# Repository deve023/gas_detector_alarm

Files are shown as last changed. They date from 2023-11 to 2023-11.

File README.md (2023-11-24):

# Gas Detector Alarm

The system has a gas detector. When gas is detected a yellow LED turns on and an alarm buzzer rings. When gas is no longer present, the LED turns off but the sound alarm remains until the user presses the deactivation button. Cost: aproximately USD 16 if the components are purchased through Amazon.

# Block Diagram

BlockDiagram

The repository contains the VHD code describing the hardware, a test bench to try out the different scenarios and the circuit diagram. 3D design of the case is pending.

# Bill of Materials

BOM

# Case Example

In this scenario, pressing the button when the alarm is off does not change the output. Once gas is detected, LED and buzzer both turn on. If gas is no longer detected, LED goes off but buzzer remains. Only when pressing the button does the buzzer turn off. Furthermore, if gas is detected when the button is on, the user must release the button and press it again to deactivate the alarm. This last functionality is set like this in case the button gets stuck, if that is the case and the user is unaware of the button's condition the alarm would go off anyway.

Example

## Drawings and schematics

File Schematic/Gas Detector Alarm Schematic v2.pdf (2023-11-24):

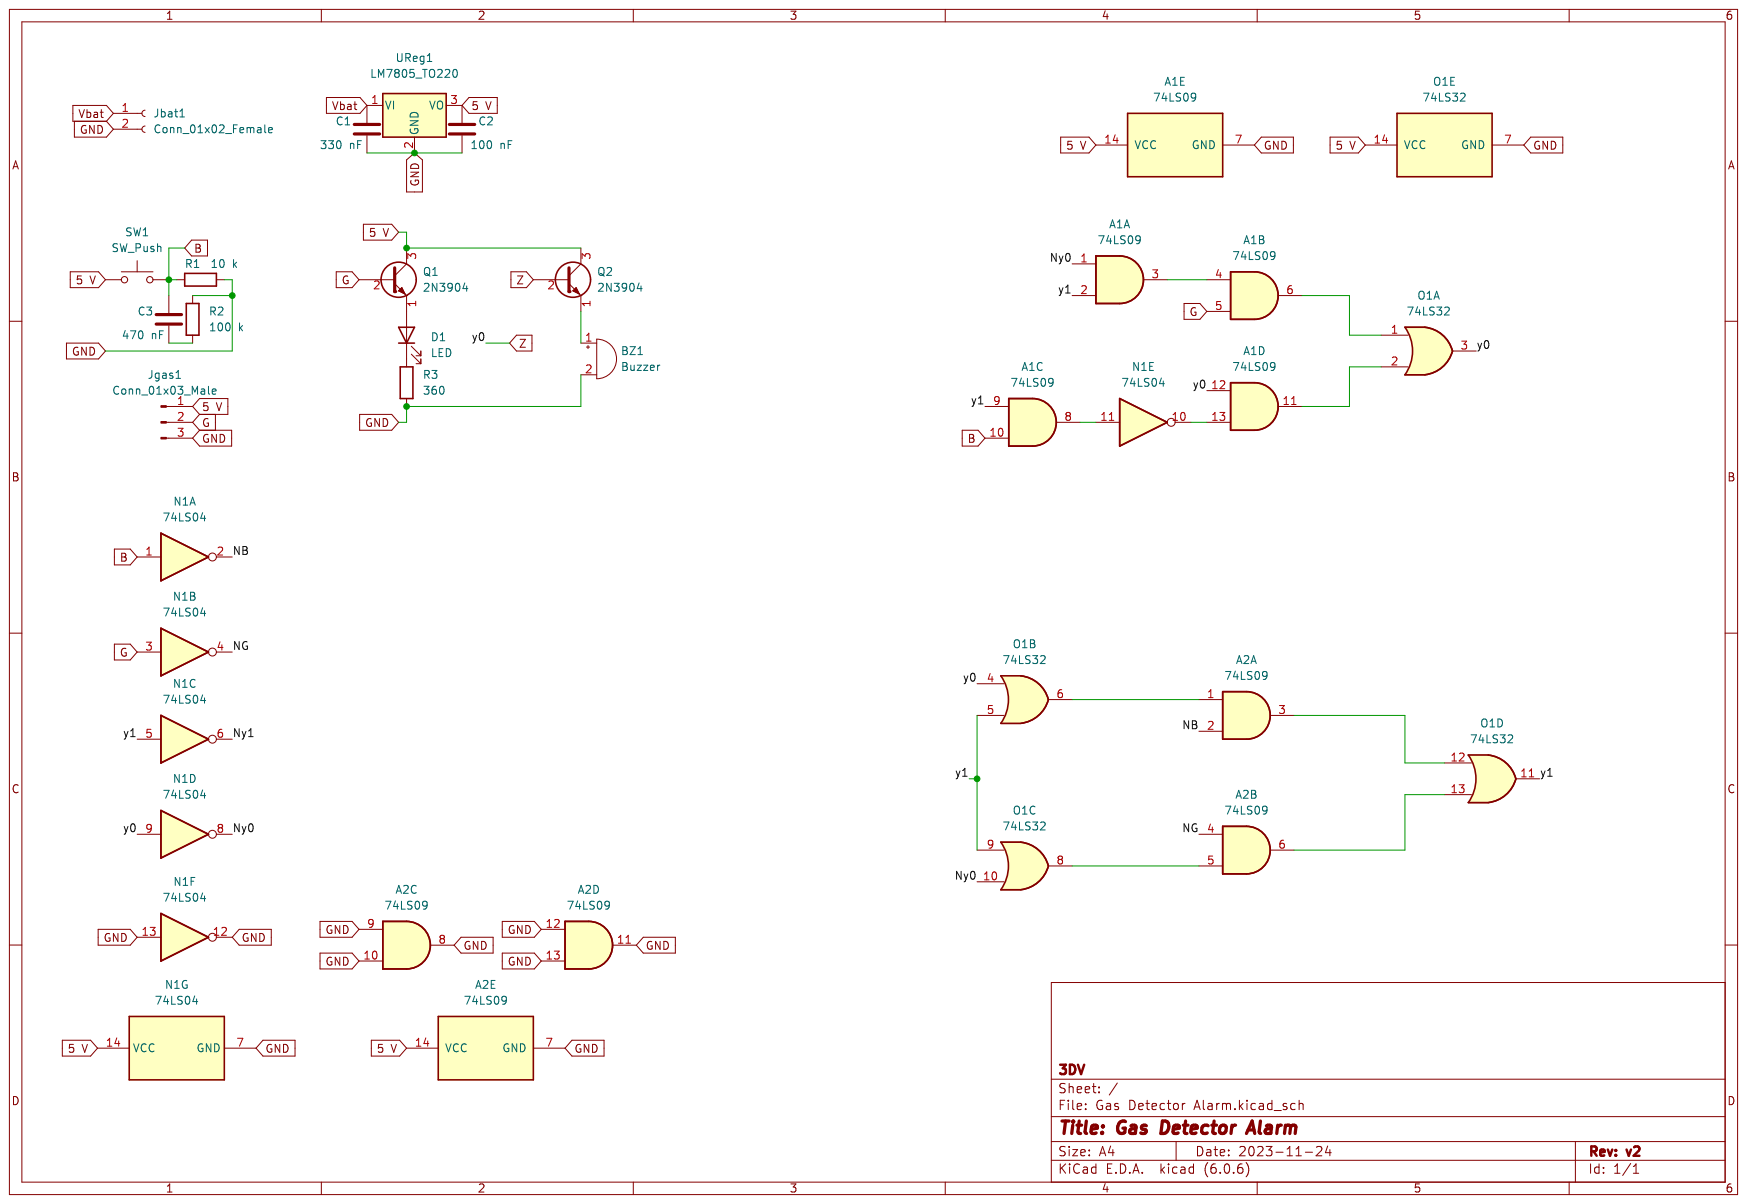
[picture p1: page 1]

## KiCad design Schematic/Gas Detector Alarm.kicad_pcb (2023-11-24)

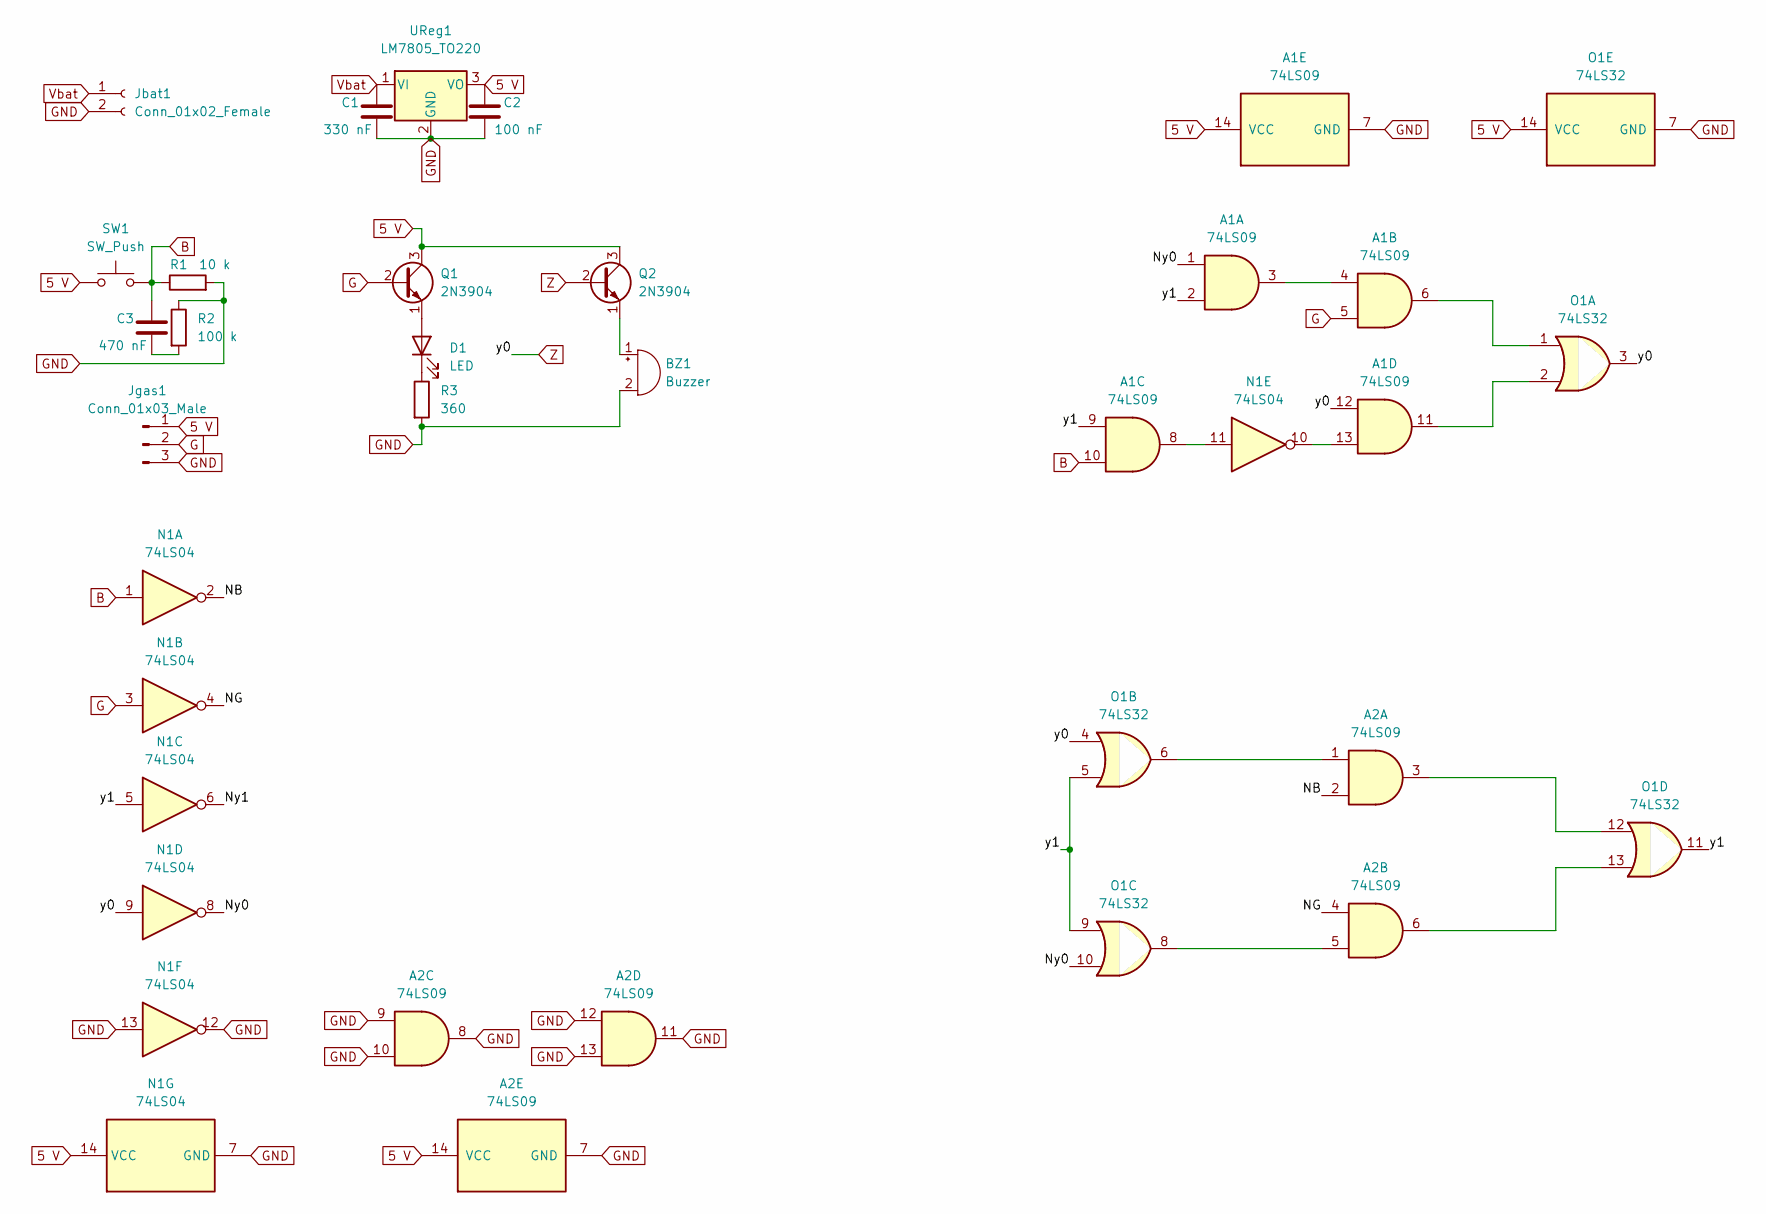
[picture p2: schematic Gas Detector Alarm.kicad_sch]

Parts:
A1, A2: 74LS09; DIP_Socket-14_W4.3_W5.08_W7.62_W10.16_W10.9_3M_214-3339-00-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
BZ1: Buzzer; Buzzer_15x7.5RM7.6
C1: 330 nF; C_Disc_D9.0mm_W5.0mm_P5.00mm
C2: 100 nF; C_Disc_D9.0mm_W5.0mm_P5.00mm
C3: 470 nF; C_Disc_D9.0mm_W5.0mm_P5.00mm
D1: LED; LED_D3.0mm
Jbat1: Conn_01x02_Female; PinSocket_1x02_P1.00mm_Vertical
Jgas1: Conn_01x03_Male; PinHeader_1x03_P1.00mm_Vertical
N1: 74LS04; DIP_Socket-14_W4.3_W5.08_W7.62_W10.16_W10.9_3M_214-3339-00-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
O1: 74LS32; DIP_Socket-14_W4.3_W5.08_W7.62_W10.16_W10.9_3M_214-3339-00-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
Q1, Q2: 2N3904; TO-92_Inline
R1: 10 k; R_Axial_DIN0207_L6.3mm_D2.5mm_P2.54mm_Vertical
R2: 100 k; R_Axial_DIN0207_L6.3mm_D2.5mm_P2.54mm_Vertical
R3: 360; R_Axial_DIN0207_L6.3mm_D2.5mm_P2.54mm_Vertical
SW1: SW_Push; SW_PUSH_6mm_H5mm
UReg1: LM7805_TO220; TO-220-3_Vertical

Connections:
5 V: A1.14 (VCC), A2.14 (VCC), C2.1, Jgas1.1, N1.14 (VCC), O1.14 (VCC), Q1.3 (C), Q2.3 (C), SW1.1, UReg1.3 (VO)
/NB: A2.2, N1.2
/NG: A2.4, N1.4
/Ny0: A1.1, N1.8, O1.10
/Ny1: N1.6
/y1: A1.2, A1.9, N1.5, O1.5, O1.9, O1.11
B: A1.10, C3.1, N1.1, R1.1, SW1.2
G: A1.5, Jgas1.2, N1.3, Q1.2 (B)
GND: A1.7 (GND), A2.7 (GND), A2.8, A2.9, A2.10, A2.11, A2.12, A2.13, BZ1.2 (+), C1.2, C2.2, Jbat1.2, Jgas1.3, N1.7 (GND), N1.12, N1.13, O1.7 (GND), R1.2, R2.1, R3.2, UReg1.2 (GND)
unnamed: A1.3, A1.4
unnamed: A1.6, O1.1
unnamed: A1.11, O1.2
unnamed: A2.1, O1.6
unnamed: A2.6, O1.13
unnamed: C3.2, R2.2
unnamed: D1.1 (K), R3.1
unnamed: D1.2 (A), Q1.1 (E)
unnamed: A1.13, N1.10
unnamed: A1.8, N1.11
unnamed: A2.5, O1.8
unnamed: A2.3, O1.12
unnamed: BZ1.1 (-), Q2.1 (E)
Vbat: C1.1, Jbat1.1, UReg1.1 (VI)
Z: A1.12, N1.9, O1.3, O1.4, Q2.2 (B)

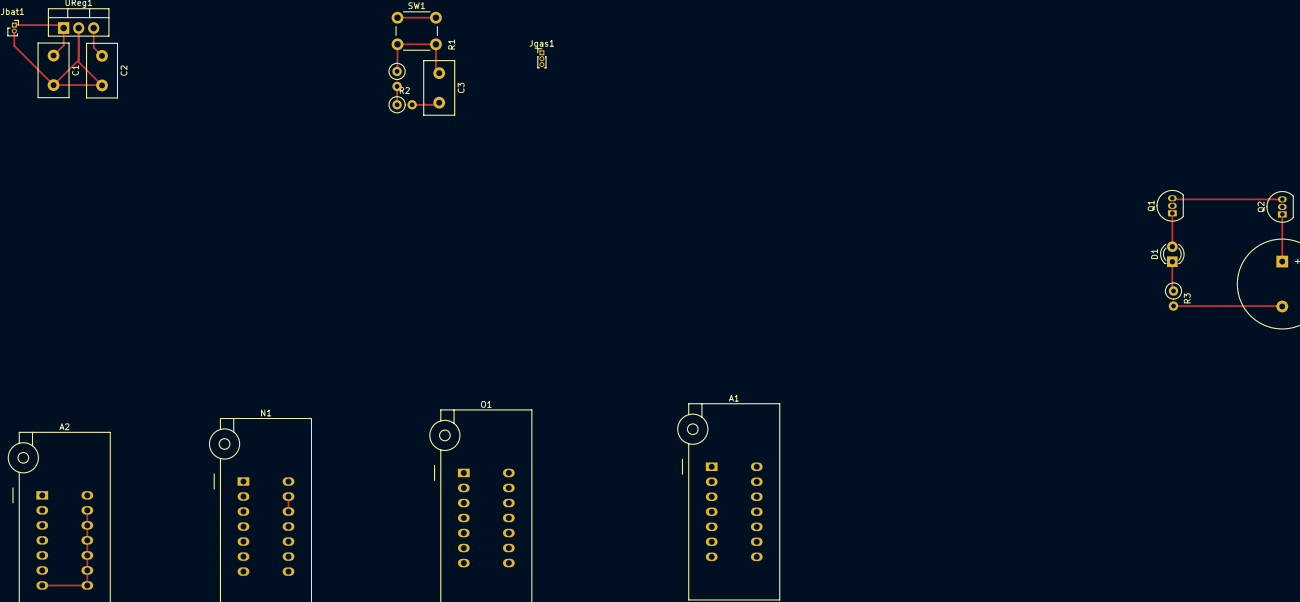
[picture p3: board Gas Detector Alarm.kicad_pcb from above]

Board: 2 copper layers, 18 parts (0 on the bottom side), 23 nets.

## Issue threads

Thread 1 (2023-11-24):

Buffer to Buzzer

deve023, 2023-11-24:
Buzzer should not be connected directly to the 74LS32 output pin.

Add a 2N3904 buffer to draw the neccessary current from the LM7805 regulator.

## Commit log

2023-11-24 Schematic upload
2023-11-24 Fixed functionality of release and press button to turn off present alarm.
2023-11-24 Schematic v2
    [Gas Detector Alarm.kicad_sch]
2023-11-24 Add PCB schematic file v1 (In progress)
    [Gas Detector Alarm.kicad_pcb]
2023-11-24 Schematic v2 in PDF for easier visualization
